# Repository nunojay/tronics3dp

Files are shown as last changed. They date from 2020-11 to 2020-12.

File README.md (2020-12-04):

# 3D Printable Electronics Related Stuff

I'll be gathering here a set of electronics related 3D printed stuff of my own design.

## 3D Printable Oscilloscope Probe Tip Cover

OpenSCAD implementation of parametric tip cover for scope probes. This is an accessory usually bundled with probes, but they're tiny and prone to be lost and, above all and in my experience, they have a section with larger diameter than the probe, which makes the set a little bit too bulky for some tight spaces (exactly where you're compelled to use a cover).

There's one (OpenSCAD) module to build the cover, ProbeTipProtection(), in ProbeTipProtectLib.scad . Then there are other files with names specific to the probe in question (there are several size probes), which invoke ProbeTipProtection() with appropriate parameters.

The STL output files for 2 protector models (with and without a metal tip long sleeve) are included, for Rigol's RP2200 probes, ready to be sliced and printed.

In the image below we have at the top the original cover and a few of the covers without the long metal tip sleeve.

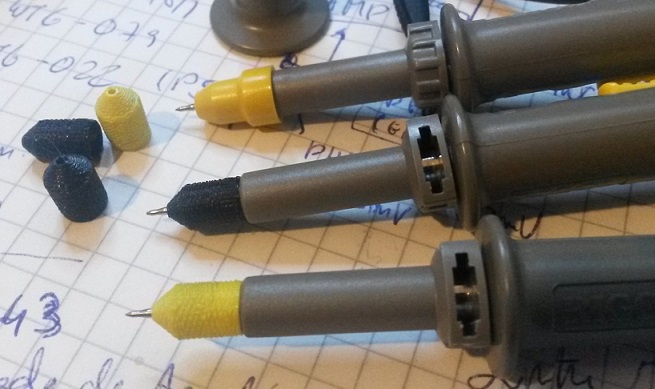
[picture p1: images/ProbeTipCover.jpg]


Product development is a set of think - design - print - test iterations.

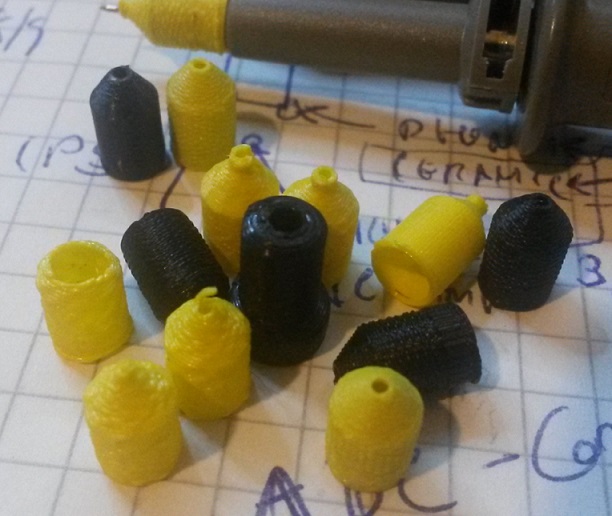
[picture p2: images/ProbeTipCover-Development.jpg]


## Printing Guidelines

I print with no supports, 0.4mm nozzle, "spiral" mode. On some slicers it helps to set the number of bottom and top layers to 0.
Printing parameters depend alot on your slicer, printer and filament. In my tests I have used Slic3r (Ultimakercura 4.6 didn't slice the long sleeve version correctly), Creality Ender 3 Pro and [Tucab's Fil3D PLA 4032D](https://www.tucab.pt/en/Fil-3D/Filamentos-3D-PLA) filament.

Before the first use, insert the probe's metal tip into the cover's hole from the outside, to finish the hole opening and line it up. Otherwise you risk rupturing the cover. Also make sure your probe's metal tip is straight, it must line up with the cover's hole.

Enjoy :)

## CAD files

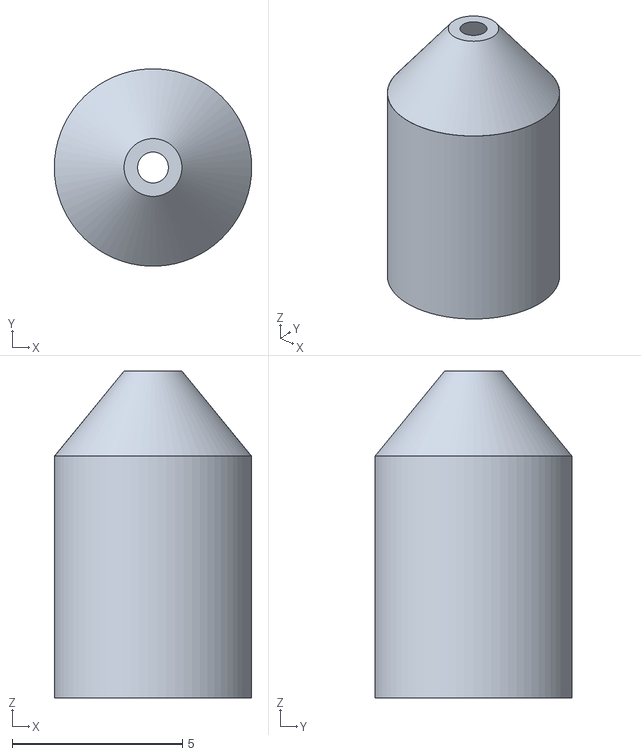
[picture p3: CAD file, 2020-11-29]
official-release-STLs/Rigol-RP2200_ProbeTipCover.stl
5.80 x 5.79 x 9.61

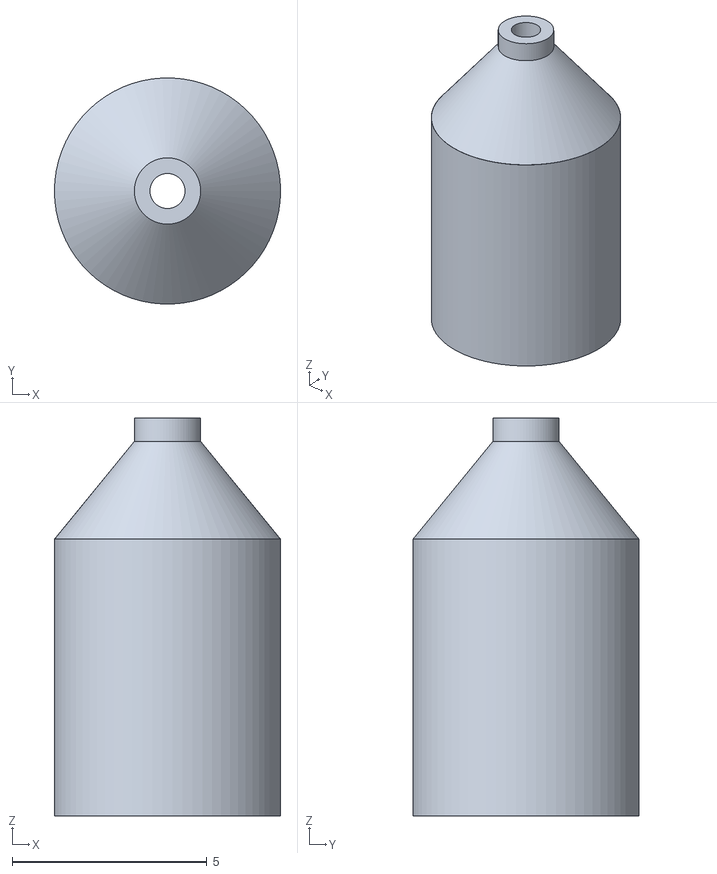
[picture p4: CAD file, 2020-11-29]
official-release-STLs/Rigol-RP2200_ProbeTipCover-LongSleeve.stl
5.80 x 5.79 x 10.2

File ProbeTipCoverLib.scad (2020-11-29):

////////////////////////////////////////////////////////////////
// Scope probe tip protection
// By Nuno João from https://EmbeddedDreams.com
// Released 2020 under Creative Commons 3.0
//
// This creates a cover to protect a scope's probe tip from
// shorting to nearby components when probing a board.
// Scope probes include this accessory, but it can be lost,
// and is tipically larger than I would like them to be...
//


// Parameter defaults are for Rigol RP2200 probes.
module ProbeTipCover (
        InnerDiameter = 5.00,
        BodyLength = 7.10,
        ConeLength = 2.50,
        TipLength = 0.00,
        TipHoleDiameter = 0.90,
        WallThickness = 0.4
)  {
    // Precalcs and other constants
    cType = 0;
    cHeight = 1;
    cDiameter = 2;
    cPreviousDiameter = 3;
    cSmoothness = 70;

    // Tip definition, by vertical segments. Types:
    //  0: cylinder
    //  1: cone, a linear transition between 2 adjacent segments
    //  2: flat, diameter is a center hole's diameter
    cSegments = [
    //  type  height       in/hole-diam      prevDiam
        [ 0,  BodyLength,  InnerDiameter                   ],
        [ 1,  ConeLength,  TipHoleDiameter,  InnerDiameter ],
        [ 0,   TipLength,  TipHoleDiameter                 ],
    ];

    // OpenSCAD's stupid concept of "variable" forces me to this (and more):
    function GetBaseHeight(idx) =
        idx < 0 ?
            0 :
            (cSegments[idx][cHeight] + GetBaseHeight(idx - 1));

    limit = len(cSegments) - 1;
    for (idx = [0 : limit])  {
        section = cSegments[idx];
        type = section[cType];
        height = section[cHeight];
        diameter = section[cDiameter];
        fn = cSmoothness;

        if (height > 0.0)  {
            if (type == 0)  {
                translate([0, 0, GetBaseHeight(idx-1)])
                    difference()  {
                        cylinder(h = height+0.006, d = diameter + WallThickness*2, $fn=fn);
                        translate([0, 0, -0.01])
                            cylinder(h = height * 0.01 + 0.02, d = diameter, $fn=fn);
                            cylinder(h = height + 0.02, d = diameter, $fn=fn);
                    }
            }
            else if (type == 1)  {
                prevDiam = section[cPreviousDiameter];
                outDiam = diameter + WallThickness*2;
                outPrevDiam = prevDiam + WallThickness*2;
                translate([0, 0, GetBaseHeight(idx-1)])
                    difference()  {
                        cylinder(h = height+0.006, d1 = outPrevDiam, d2 = outDiam, $fn=fn);
                        translate([0, 0, -0.01])
                            cylinder(h = height + 0.02, d1 = prevDiam,
                                                        d2 = diameter, $fn=fn);
                    }
            }
            else if (type == 2)  {
                holeDiam = section[cDiameter2];
                echo("hole diam: ", holeDiam);
                translate([0, 0, GetBaseHeight(idx-1) - WallThickness])
                    difference()  {
                        // The flat top slab
                        cylinder(h = WallThickness+0.006, d = diameter + 0.6, $fn=fn);
                        // Hole in the center
                        translate([0, 0, -0.005])
                            cylinder(h = WallThickness*2 + 0.01, d = holeDiam, $fn=fn);
                    }
            }
            else  {
                echo("***** UPS!! Unkonwn type!");
            }
        }
    }
}


/// Test
//ProbeTipCover();

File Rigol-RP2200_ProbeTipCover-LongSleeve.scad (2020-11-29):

include <ProbeTipCoverLib.scad>;

// Build it!
// Note: InnerDiameter should be 4.7 - 4.8, but it simply doesn't fit,
// maybe something with my printer.
ProbeTipCover(
        InnerDiameter = 5.00,
        BodyLength = 7.10,
        ConeLength = 2.50,
        TipLength = 0.60,
        TipHoleDiameter = 0.90
);

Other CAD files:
ProbeTipProtectLib.scad
Rigol-RP2200_ProbeTipCover.scad
Rigol-RP2200_ProbeTipProtect-LongTip.scad
Rigol-RP2200_ProbeTipProtect.scad

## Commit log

2020-11-29 First functional version.
    [ProbeTipProtectLib.scad, Rigol-RP2200_ProbeTipProtect-LongTip.scad, Rigol-RP2200_ProbeTipProtect-LongTip.stl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]
2020-11-29 Names and doc changes.
    [ProbeTipCoverLib.scad, Rigol-RP2200_ProbeTipCover-LongSleeve.scad, Rigol-RP2200_ProbeTipCover-LongSleeve.stl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]
2020-11-29 Doc update.
    [Rigol-RP2200_ProbeTipCover-LongSleeve.scad, Rigol-RP2200_ProbeTipCover.scad]
